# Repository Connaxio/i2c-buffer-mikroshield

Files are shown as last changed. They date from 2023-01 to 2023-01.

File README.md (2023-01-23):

# I2C Buffer mikroShield

This mikroBUS-compatible mikroShield protects a mainboard's power and I2C lines when connecting unpowered off-board devices. For self-powered devices, an isolated adapter board is preferred.

## Features

- PTC resettable fuse on the 5 V supply rail (200 mA hold, 400 mA trip)
- Dedicated 3.3 V linear regulator from the protected 5 V rail
- I2C buffer / repeater (5500 V HBM ESD)
- ESD protection (TVS) diodes on external SCL, SDA, and 3.3V supply lines
- Series current-limiting resistors on the SCL and SDA external signal lines
- 100 mils output connector compatible with Grove, quiic, and STEMMA adapter boards for a direct board-to-board connection.

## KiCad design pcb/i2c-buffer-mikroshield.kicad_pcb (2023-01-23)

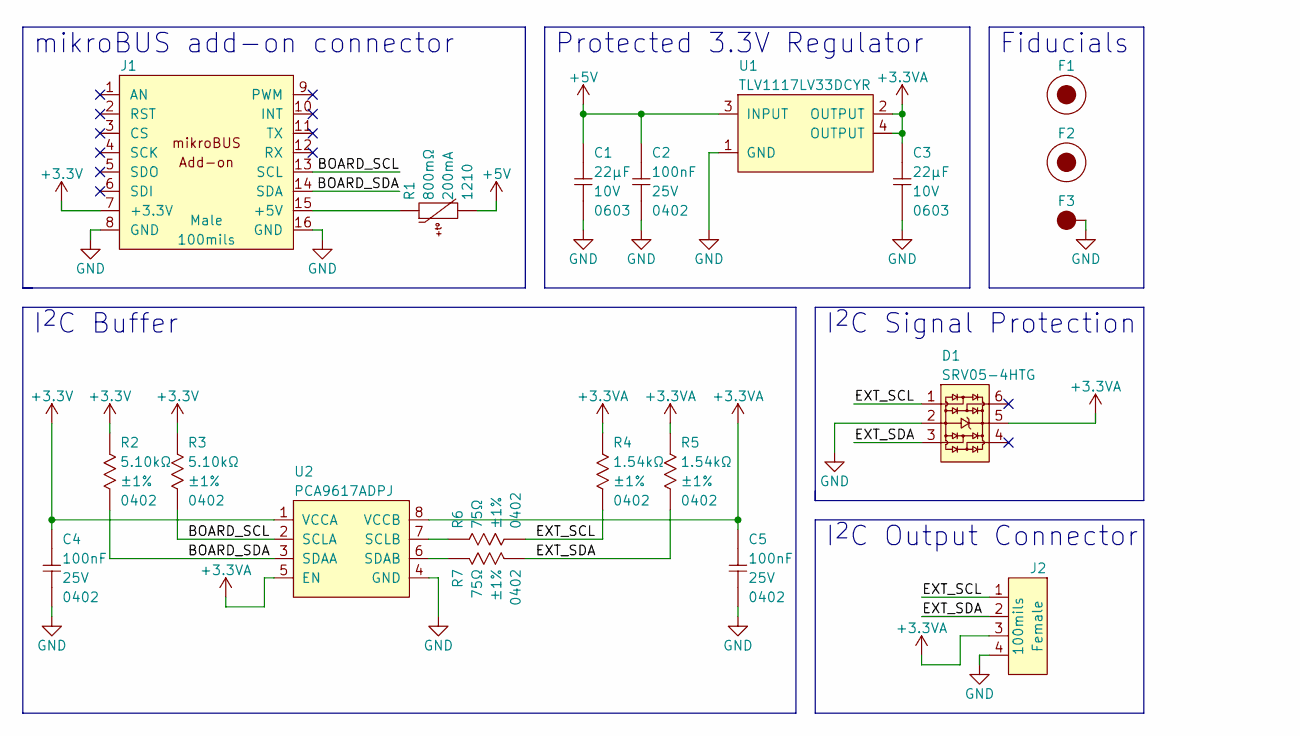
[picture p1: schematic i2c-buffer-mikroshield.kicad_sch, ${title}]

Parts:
C1, C3: CAP_CER_22UF_10V_0603; CAP_CER_0603_1608M; Tolerance ±20%; Voltage 10V; Manufacturer Part Number CL10A226MP8NUNE
C2, C4, C5: CAP_CER_100NF_25V_0402; CAP_CER_0402_1005M; Tolerance ±10%; Voltage 25V; Manufacturer Part Number CL05A104KA5NNNC
D1: DIO_TVS_SRV05-4HTG; SOT-23-6; Voltage 6V; Manufacturer Part Number SRV05-4HTG
F1, F2: FID_1X3
F3: FID_1X1
J1: CON_HDR_MIKROBUS_ADDON_TH; Voltage 350V
J2: CON_HDR_100MILS_F_TH_RA_1X4; Voltage 350V
R1: PTC_SMD1210B010TF; RES_1210_3225M; Tolerance 400mA; Voltage 30V; Manufacturer Part Number SMD1210B010TF
R2, R3: RES_5.10KΩ_1%_0402; RES_0402_1005M; Tolerance ±1%; Voltage 50V; Manufacturer Part Number RMCF0402FT5K10
R4, R5: RES_1.54KΩ_1%_0402; RES_0402_1005M; Tolerance ±1%; Voltage 50V; Manufacturer Part Number RMCF0402FT1K54
R6, R7: RES_75Ω_1%_0402; RES_0402_1005M; Tolerance ±1%; Voltage 50V; Manufacturer Part Number RMCF0402FT75R0
U1: REG_LDO_TLV1117LV33DCYR; SOT-223-4; Voltage 5.5V; Manufacturer Part Number TLV1117LV33DCYR
U2: BUF_I2C_PCA9617ADPJ; TSSOP-8_3X3_P0.65; Voltage 2.7V to 5.5V; Manufacturer Part Number PCA9617ADPJ

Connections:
+3.3V: C4.1, J1.7 (+3.3V), R2.1, R3.1, U2.1 (VCCA)
+3.3VA: C3.1, C5.1, D1.5, J2.3, R4.1, R5.1, U1.2 (OUTPUT), U1.4 (OUTPUT), U2.5 (EN), U2.8 (VCCB)
+5V: C1.1, C2.1, R1.2, U1.3 (INPUT)
/BOARD_SCL: J1.13 (SCL), R3.2, U2.2 (SCLA)
/BOARD_SDA: J1.14 (SDA), R2.2, U2.3 (SDAA)
/EXT_SCL: D1.1, J2.1, R4.2, R6.2
/EXT_SDA: D1.3, J2.2, R5.2, R7.2
GND: C1.2, C2.2, C3.2, C4.2, C5.2, D1.2, F3.1, J1.8 (GND), J1.16 (GND), J2.4, U1.1 (GND), U2.4 (GND)
unnamed: J1.15 (+5V), R1.1
unnamed: R7.1, U2.6 (SDAB)
unnamed: R6.1, U2.7 (SCLB)

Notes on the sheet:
I^{2}C Buffer
I^{2}C Signal Protection
Fiducials
I^{2}C Output Connector
Protected 3.3V Regulator
mikroBUS add-on connector

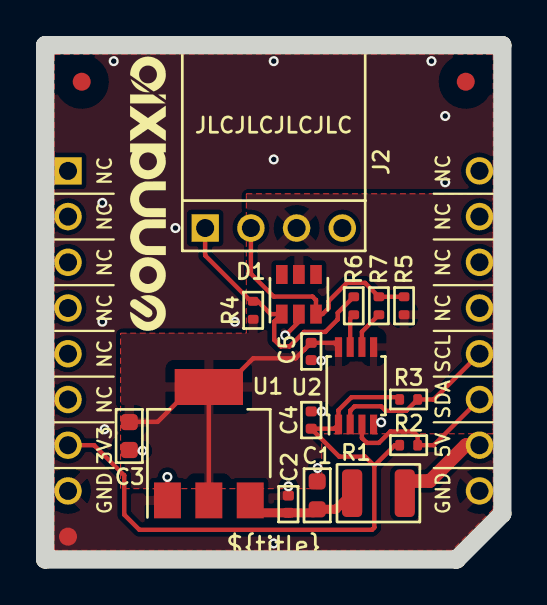
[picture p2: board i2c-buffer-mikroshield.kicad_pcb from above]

Board: 2 copper layers, 25.4 x 28.6 mm, 20 parts (0 on the bottom side), 11 nets.

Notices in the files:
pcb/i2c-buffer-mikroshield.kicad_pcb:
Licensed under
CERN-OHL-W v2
